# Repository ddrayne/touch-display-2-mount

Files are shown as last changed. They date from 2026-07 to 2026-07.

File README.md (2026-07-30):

# touch-display-2-mount

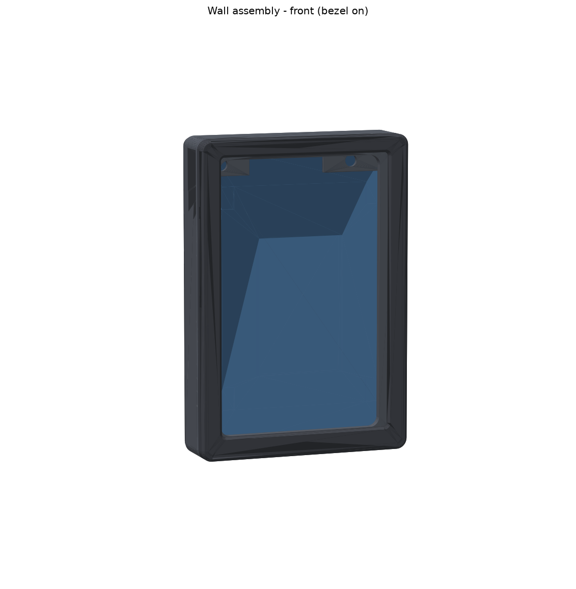
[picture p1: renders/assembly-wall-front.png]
Wall assembly


3D-printed mounts for the **Raspberry Pi Touch Display 2 – 10″ Portrait**
(with a Raspberry Pi 5 on its back): a three-part **gallery shadow-box wall
frame** (body + snap-on bezel + rear cover) that makes the display read as
framed art — ideal for dashboards, photo frames, and home-automation panels
— and a one-piece **desk stand**, plus two quick corner **fit coupons**.

Every dimension derives from the official product brief
(`docs/touch-display-2-10in-product-brief.pdf`, RP-010276-MM-1-10, July
2026), transcribed into `src/spec.py` — **with one measured correction: a
production unit is ~167 mm wide, not the drawing's 161.76** (the brief
itself warns its dimensions are approximate; height and active area check
out). If your unit differs, set `spec.UNIT_W` from calipers and rebuild.
The transcription was independently audited against the
drawing, and re-measured from the exported STLs by `src/verify.py` on every
build — including **assembly-path sweeps** that prove the display, bezel,
and cover can physically be installed and removed.

## Parts

**Slicing? Import the files in `print/`** — they are pre-rotated so the
correct face lands on the plate as imported (the `stl/` copies are in the
CAD's canonical coordinates for the verification harness and would import
three parts upside-down).

| File | What | Print orientation |
|---|---|---|
| `stl/frame.stl` | Wall-frame body, 174.2 × 254.53 × 45.8 mm | **Rear-face-down** (as exported) |
| `stl/bezel.stl` | Snap-on front bezel (the visible frame face) | Face-down (as exported) |
| `stl/cover.stl` | Posts-only vented rear cover | Rear-face-down |
| `stl/stand.stl` | Desk stand, 15° easel lean | Plate-face-down (as exported) |
| `stl/fit-coupon-body.stl` + `stl/fit-coupon-bezel.stl` | Corner fit gauges — **print these first** | As exported |
| `stl/_display_reference.stl` | Display solid for CAD reference — **do not print** | — |

3MF copies of each part sit alongside the STLs.

## How it works

The wall mount is **front-loading**. The body is an open-fronted shadow box
with an internal shelf ring; the display — with the Pi 5 already screwed to
its rear standoffs and protruding backward — drops in from the front and
its chassis rim rests on the shelf (the depth datum). The **bezel** then
slides over the body's recessed front band and clicks onto nine snap nubs
riding compliant tongues; foam pads on its back press the glass onto the
shelf. The lap seam between bezel skirt and body reads as a deliberate
1.5 mm shadow reveal around the frame.

The Pi + Active Cooler live in the deep, hidden cavity behind the shelf,
washed by seven hidden vent slots per side. The small **cover** enters
through the rear opening (passing under the keyhole tabs), lands on the
display's four M2.5 bobbin posts (121.8 × 160 mm pattern), and takes four
of the display's own supplied screws — it tidies the back, carries zip-tie
anchors, and lets the USB-C lead run to the bottom cable slot.

The rear edge carries a 6 mm shadow-wedge chamfer, so the hung frame
appears to float off the wall — and the side vents exhaust into that
hidden wedge while bottom-wall slots draw intake air, giving the Pi a
proper convection path. The frame hangs on **two wall screws 110 mm
apart** via keyhole tabs printed solidly into the rear face (print `docs/drilling-template.pdf` at 100 %
scale for the wall marks). The **desk stand** screws straight onto the same
four posts and leans the display 15° on curved easel cheeks, bottom edge
floating 14 mm above the desk, cable dropping through a notch in the tie
bar.

## Bill of materials

| Qty | Item | Used for |
|---|---|---|
| 1 | Raspberry Pi Camera Module 3 (standard, optional) | viewer-facing camera in the chin pod |
| 1 | Camera adapter cable for Pi 5 (standard-to-mini), 200 mm | Cam3 to the Pi 5's free MIPI port; routed length is ~125 mm, so 200 mm is ideal (the cable in the Cam3 box does not fit a Pi 5) |
| 4 | M2 × 4 mm self-tapping screws | camera board into the pod bosses |
| 4 | M2.5 screws — **the display's own supplied screws fit** | cover → display posts (or stand → posts) |
| 2 | 4 mm / #8 pan-head wall screws + plugs | hanging the frame |
| 8 | soft EVA foam pads, 2 mm thick, ~15 × 8 mm self-adhesive | bezel back, around the opening (compressed to ~1 mm) |
| 2–4 | small zip ties | cable dressing on the cover |
| 4 | stick-on rubber feet (optional) | stand feet |

No other fasteners: the bezel presses on — nine snap nubs ride compliant
tongues hidden in the body's front band, so it clicks home with fingertip
force and pulls off with a firm, even tug (start at the two finger reliefs
under the bottom edge). **Only ever remove the bezel with the frame on a
bench, face up — never on the wall** (with the bezel off, nothing retains
the display).

## Print settings (Bambu X1 / P1 / A1, 0.4 mm nozzle)

| | frame (body) | bezel (+ coupons) | cover | stand |
|---|---|---|---|---|
| Material | **PETG** | PETG (match body) | PETG | PLA or PETG |
| Layer / first | 0.20 / 0.20 | 0.20 / 0.20 | 0.20 / 0.20 | 0.20 / 0.25 |
| Walls | 4 | 4 | 3 | 4 |
| Infill | 15 % gyroid | 20 % | 25 % grid | 15 % gyroid |
| Supports | **OFF** | **OFF** | **OFF** | **OFF** |
| Brim / skirt / draft shield | **all OFF — mandatory** (254.5 mm part; paint-on brim ears in ±X only if wanted) | all OFF (same footprint) | off | off |
| Plate | textured PEI | **textured PEI** (this face is the visible front) | any | any |
| Special | disable X1 flow-calibration lines / check the A1 prime line in preview; place at bed centre manually; keep the seam OFF the snap nubs (paint it onto a corner) | elephant-foot comp ≤ 0.15; seam on a corner, off the recesses | 4 bottom layers (counterbore bridges); M2.5 heads sit ~0.4 mm proud of the shallow counterbores (hidden, harmless) | full fan above z ≈ 90 (thin prongs) |

- Everything is designed support-free **in the stated orientation**; the
  only down-facing features are deliberate short bridges (vent roofs, cable
  slot end, counterbore floors, liner-groove ceiling) verified by the
  overhang census in `verify.py`.
- Holes are pre-compensated +0.25 mm (community mounts for this display
  printed M2.5 holes undersized). Keyholes are Ø10 entry / 5 mm slot with
  lead-in chamfers.
- A matte filament hides layer sheen; the bezel's face picks up the plate
  texture, so a textured plate gives it a uniform powder-coat look.
- **Bambu Handy note:** Handy can't toggle brim/skirt on a raw STL — slice
  in Bambu Studio (or a MakerWorld draft) with the settings above, then
  send to the printer; Handy is fine for monitoring.

**Print the two fit coupons first** (~1.5 h) — and treat them as
measurement artifacts, not feel-tests: print them with the *identical*
material, profile, and plate you'll use for the real parts, caliper their
62 mm edges, and set the filament's shrinkage compensation from the
measured percentage before slicing the body and bezel (a coupon that feels
"snug but OK" can still bind over the full 254 mm). Then check the display
corner's slip fit, shelf seat, bezel lap and snap click. Too tight →
raise `spec.FIT_CLEAR` (display) or `params.LAP_CLEAR` (bezel); loose →
lower them; rebuild and re-print the coupons.

**Body and bezel must be printed in the same material, same profile, same
plate** — a PLA-on-PETG pairing can eat the entire 0.25 mm lap clearance
through differential shrinkage.

## Assembly (wall frame)

1. Stick the eight foam pads to the bezel's back face around the opening
   (over the bezel's solid border, outside the visible 2.5 mm reveal).
2. Screw the Pi 5 to the display's standoffs (supplied screws), connect the
   GPIO power lead and DSI ribbon.
3. Body face-up on the bench: lower the display in, glass up — chin (wider
   bezel) toward the cable slot — until the rim rests on the shelf.
4. Fit the cover through the rear opening onto the four posts; drive four
   supplied M2.5 screws. Zip-tie the USB-C lead to the anchors, out the
   bottom slot.
5. Press the bezel on until all nine nubs click.
6. Wall: print `docs/drilling-template.pdf` at 100 %, level it, drill/plug,
   leave the two screw heads ~4 mm proud, hang and slide down.

For the stand: same steps 2, then screw the stand plate onto the posts
(supplied screws) and route the cable through the tie-bar notch.

## Camera chin pod (optional)

`print/camera-pod.stl` (~20 g, ~1 h) hangs a Camera Module 3 under the
frame's chin, facing the viewer — ideal for presence-detection backlight
wake. No frame changes: two J-hooks tilt into the frame's inner pair of
bottom intake vents and gravity locks them (lift the pod's nose to remove).
Mount the camera board **ribbon-up** on the four M2 bosses (flip the image
in software: `libcamera` rotation 180), run the mini ribbon up the pod's
concealed tail channel and through the frame's cable slot to the Pi's free
MIPI port — connect it before hanging the frame. The lens aperture clears
the full 75° field of view (verified against pod, frame, and bezel).

## Care notes

- The stand tolerates normal touch use; very firm jabs at the top edge can
  rock any 15° easel — use the wall mount for enthusiastic households.
- A right-angle USB-C plug keeps the cable exit tidy on both mounts
  (straight plugs also fit — 13 mm of window clearance each side).

## Rebuilding / customising

```bash
pip install build123d trimesh shapely networkx rtree scipy matplotlib
cd src
python3 build_all.py     # builds STL+3MF, verifies (75 checks), renders
```

`src/spec.py` is the display (don't touch unless the drawing changes);
`src/params.py` is the design — reveal, wall, depth, tilt, clearances, snap
engagement — edit freely and rebuild; verification catches anything
unprintable, un-assemblable, or spec-breaking.

## Verification

- `src/verify.py`: 75 mesh-measured checks — integrity, the 121.8 × 160
  pattern position *and* diameters, bezel opening vs active area, shelf and
  felt datums, keyhole geometry incl. slot direction, bed fit, per-part
  overhang census, boolean interference against a worst-case display solid
  (which is itself audited against the spec), and translation sweeps along
  every assembly path. Report: `docs/verification-report.json`.
- Three independent multi-agent review rounds audited the drawing
  transcription, the STLs, printability, and the design; round 1's findings
  (including an assembly-impossibility proof against the v1 architecture)
  drove the current front-loading design.

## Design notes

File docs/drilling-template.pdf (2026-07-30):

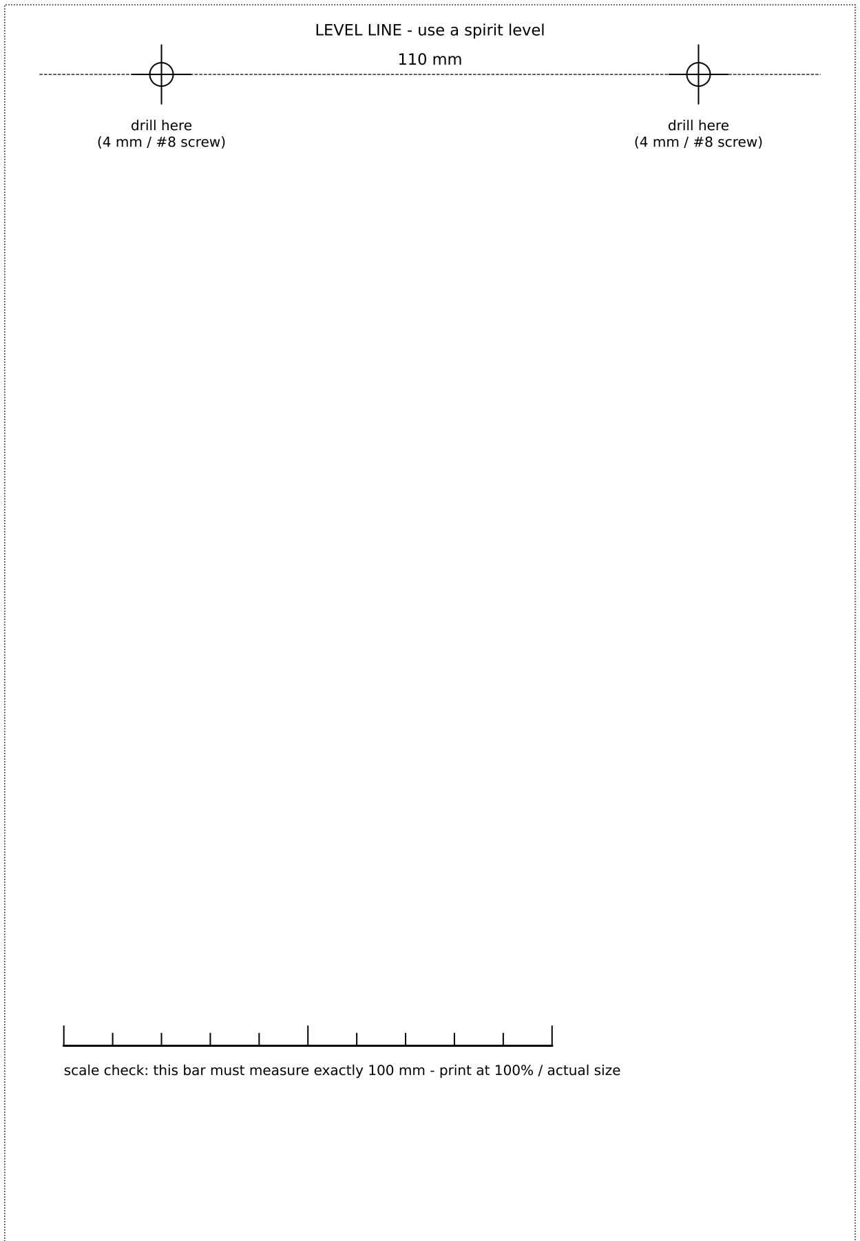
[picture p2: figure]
drill here (4 mm / #8 screw); LEVEL LINE - use a spirit level 110 mm

scale check: this bar must measure exactly 100 mm - print at 100% / actual size

Wall drilling template - Raspberry Pi Touch Display 2 10" Portrait mount Leave screw heads ~4 mm proud of the wall, hang the frame, slide down to lock.

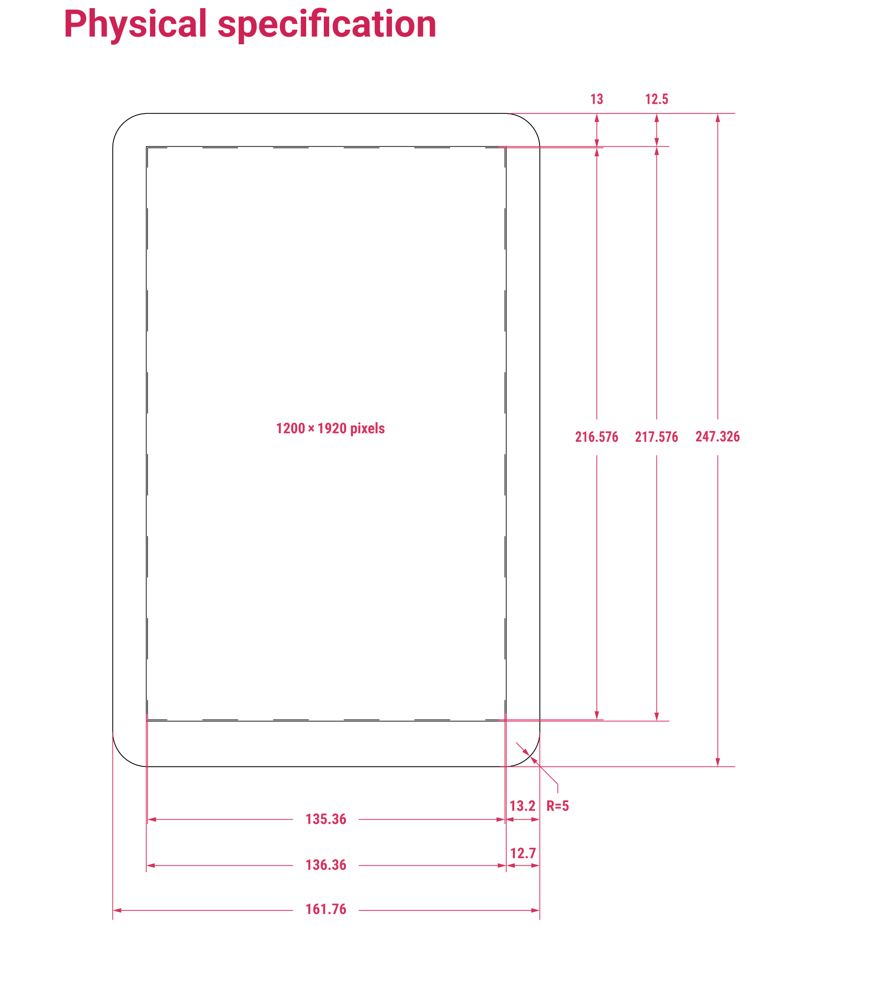
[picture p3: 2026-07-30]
docs/crop-front.png

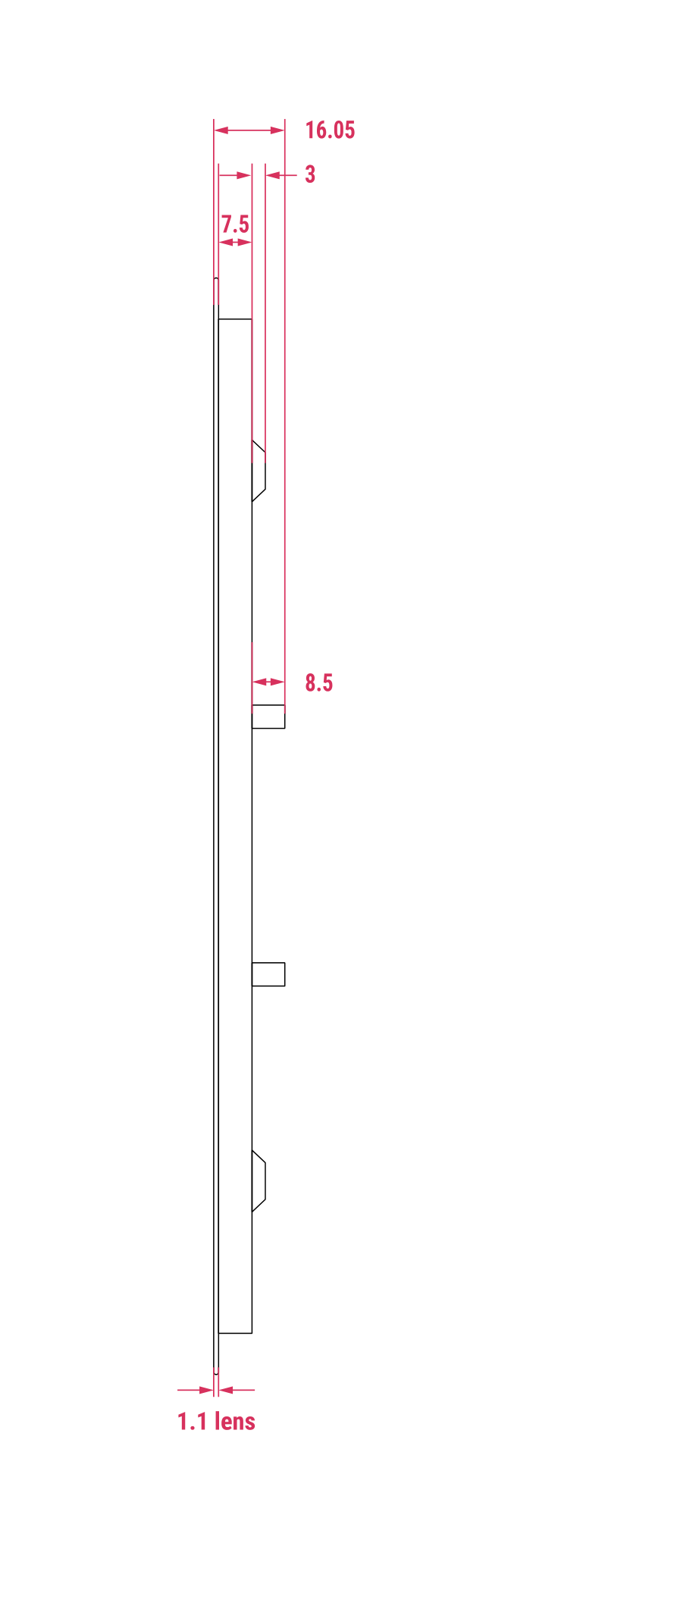
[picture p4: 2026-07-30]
docs/crop-side.png

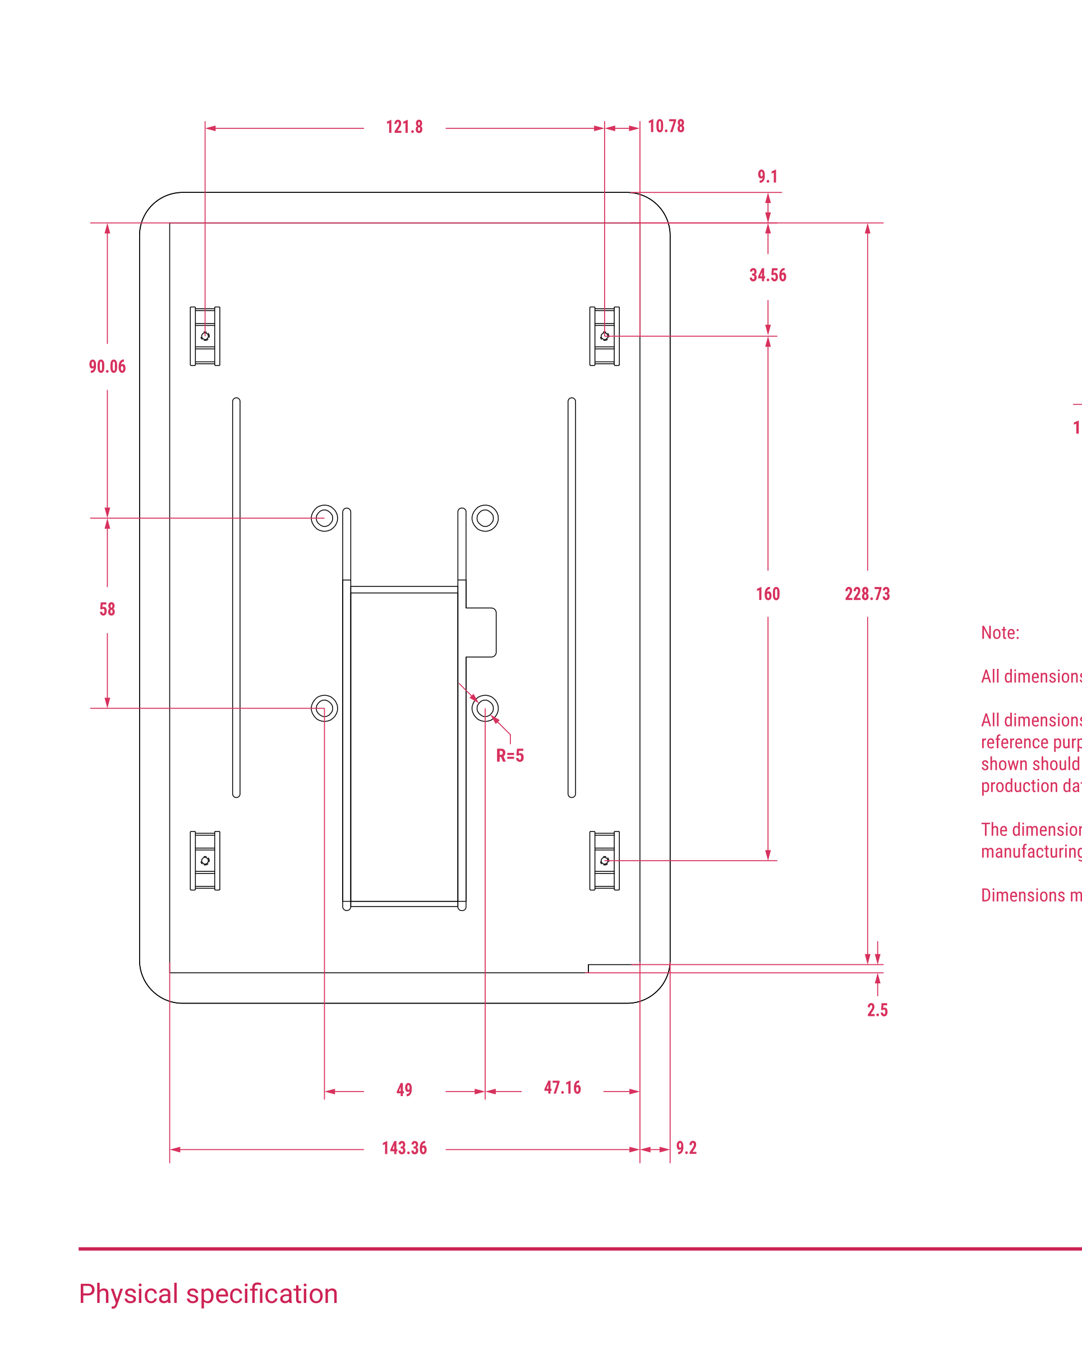
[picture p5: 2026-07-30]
docs/crop-rear.png

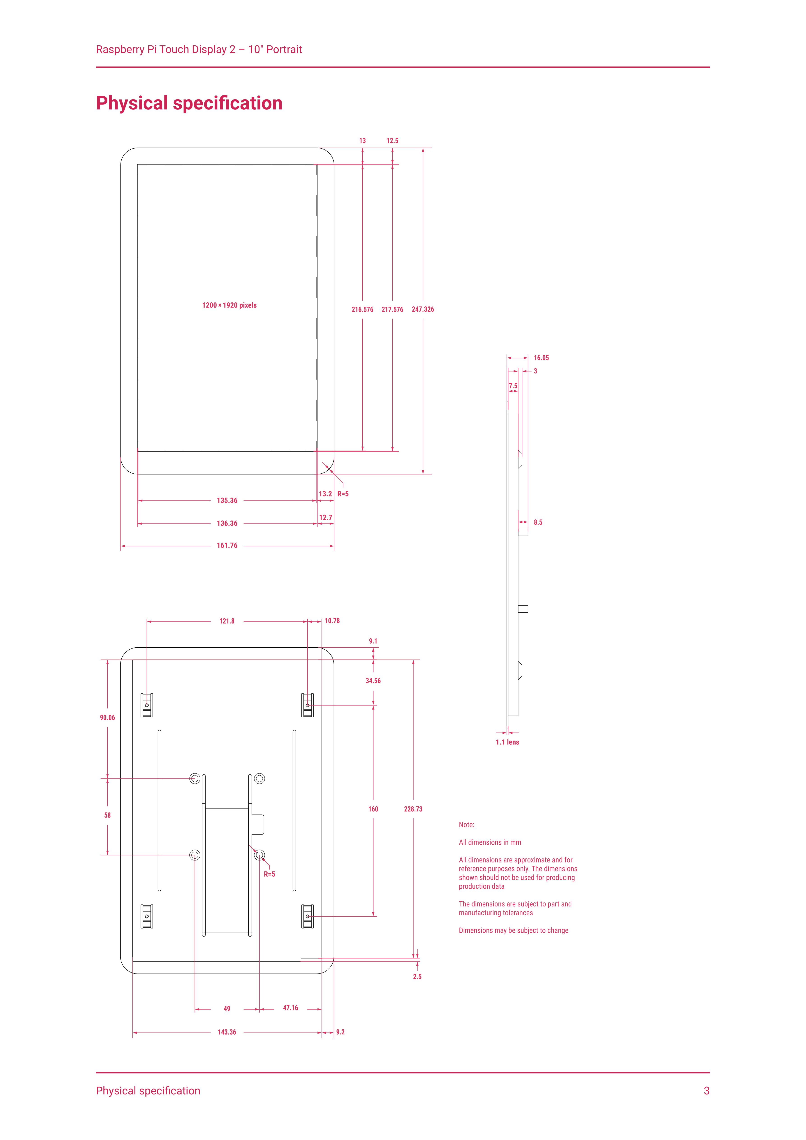
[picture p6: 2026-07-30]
docs/drawing-p4-full.png

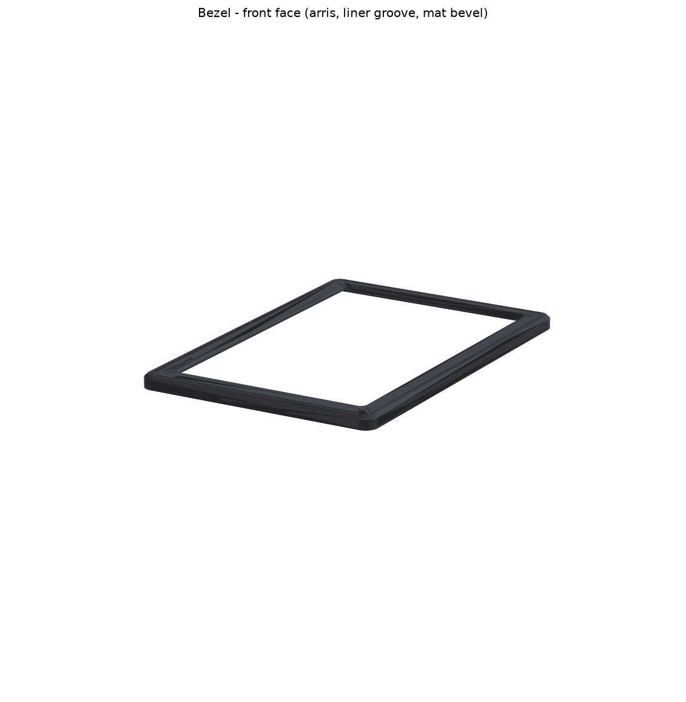
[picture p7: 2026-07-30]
renders/bezel-front.png

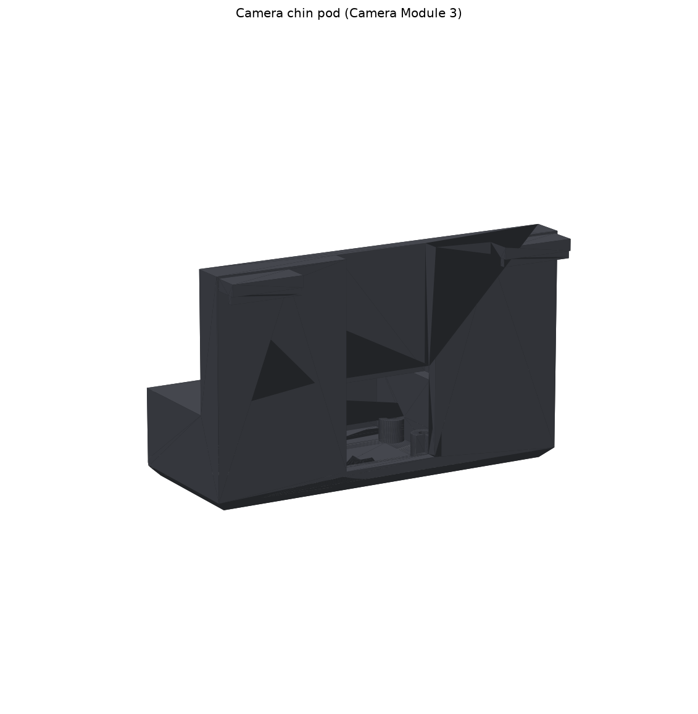
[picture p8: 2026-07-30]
renders/camera-pod.png

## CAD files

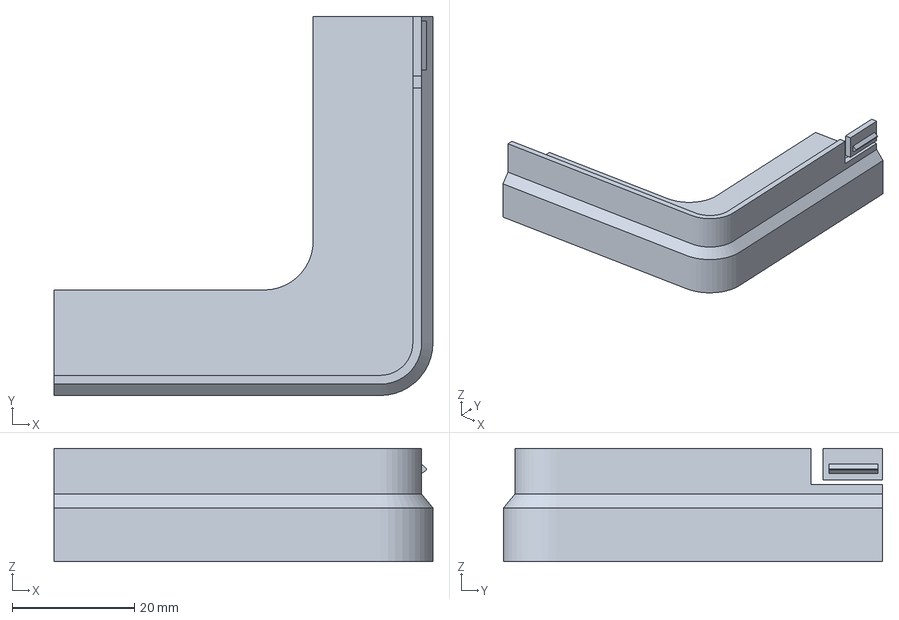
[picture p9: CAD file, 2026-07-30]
print/fit-coupon-body.3mf
62.0 x 62.0 x 18.5 mm

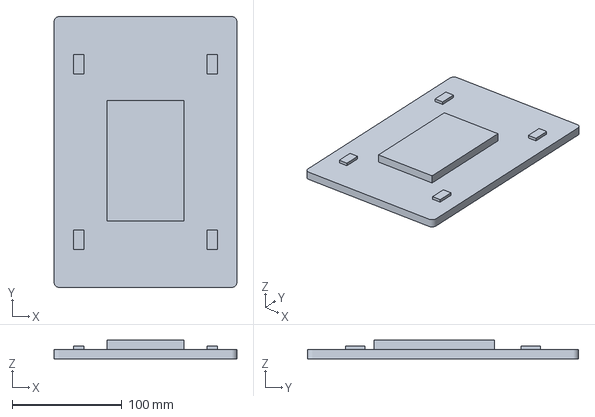
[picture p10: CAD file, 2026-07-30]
stl/_display_reference.3mf
167.0 x 247.3 x 17.1 mm

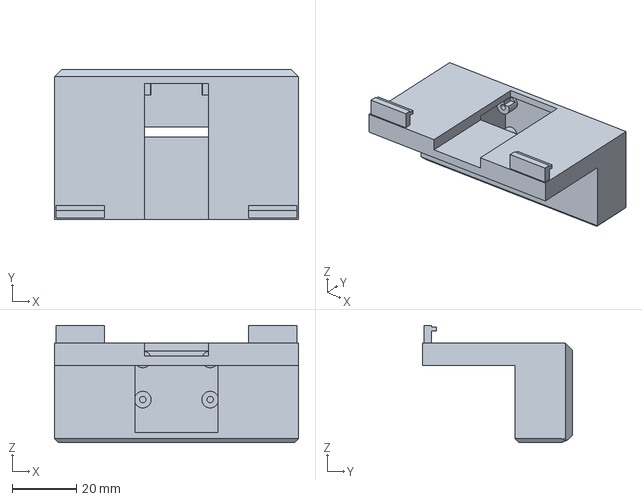
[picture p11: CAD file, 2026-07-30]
print/camera-pod.3mf
76.0 x 46.8 x 36.5 mm

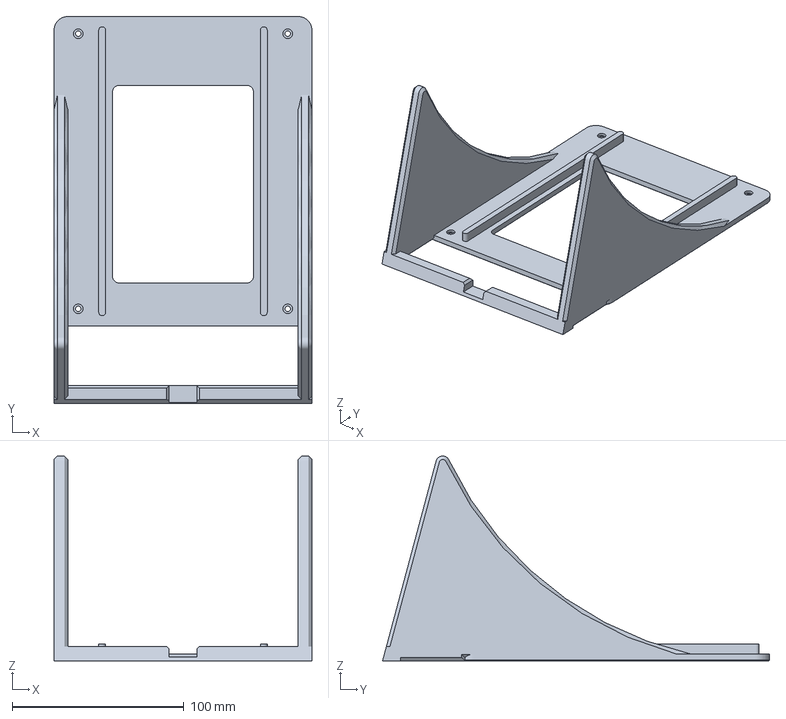
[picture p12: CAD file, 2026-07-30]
print/stand.3mf
150.0 x 225.0 x 119.2 mm

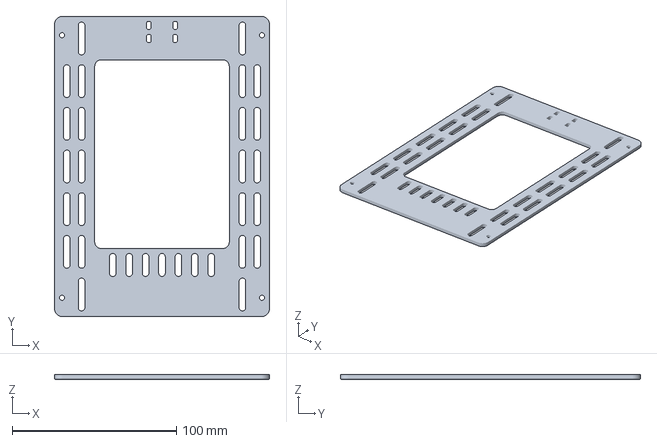
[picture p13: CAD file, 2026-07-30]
print/cover.3mf
131.0 x 183.0 x 3.00 mm

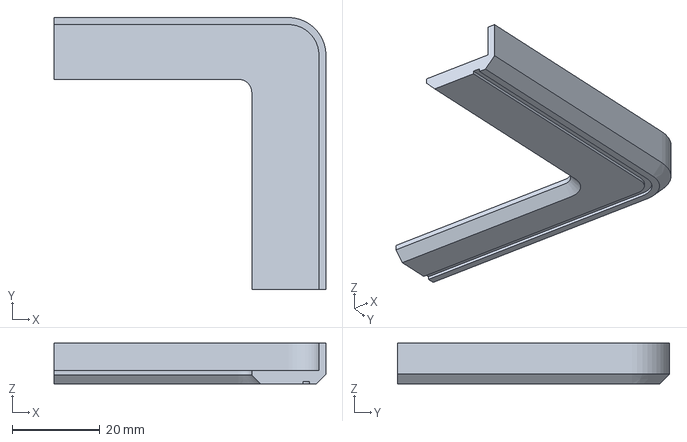
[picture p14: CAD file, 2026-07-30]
print/fit-coupon-bezel.3mf
62.0 x 62.0 x 9.30 mm

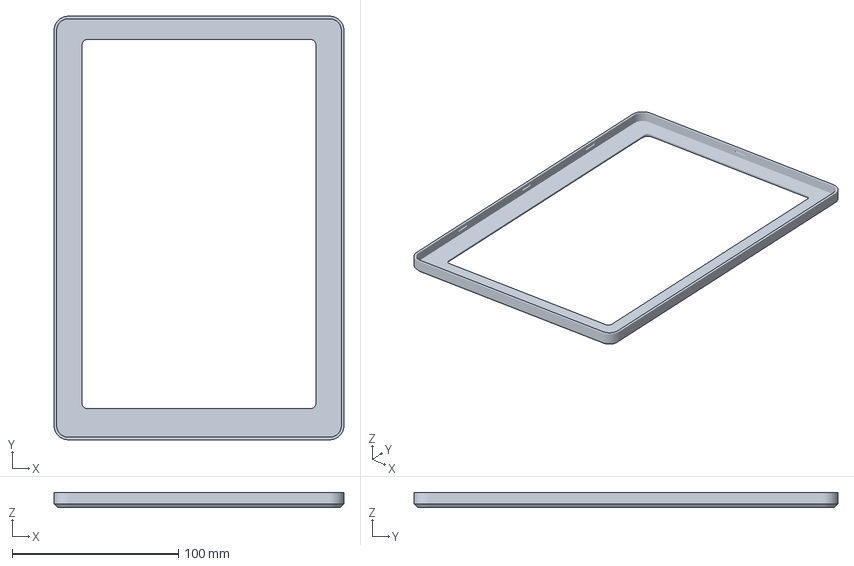
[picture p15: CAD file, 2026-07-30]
print/bezel.3mf
174.2 x 254.5 x 9.30 mm

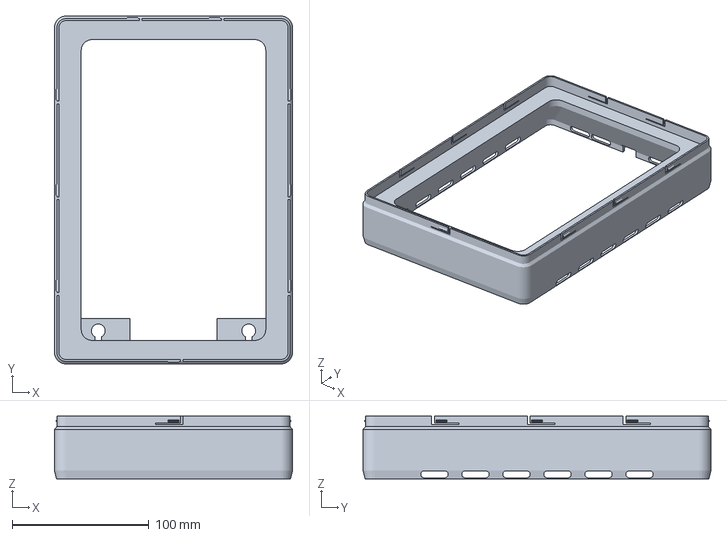
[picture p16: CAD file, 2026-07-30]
print/frame.3mf
174.2 x 254.5 x 45.8 mm

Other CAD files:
print/bezel.stl
print/camera-pod.stl
print/cover.stl
print/fit-coupon-bezel.stl
print/fit-coupon-body.stl
print/frame.stl
print/stand.stl
stl/_display_reference.stl
stl/bezel.3mf
stl/bezel.stl
stl/camera-pod.3mf
stl/camera-pod.stl
stl/cover.3mf
stl/cover.stl
stl/fit-coupon-bezel.3mf
stl/fit-coupon-bezel.stl
stl/fit-coupon-body.3mf
stl/fit-coupon-body.stl
stl/frame.3mf
stl/frame.stl
stl/stand.3mf
stl/stand.stl

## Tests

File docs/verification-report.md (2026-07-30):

# Verification history (Touch Display 2 10-inch mount)

The machine-readable current status lives in `verification-report.json`
(written by `src/verify.py` on every build). This file records the
independent review rounds and what they changed.

## Round 0 — spec transcription audit (before any CAD)

An independent reader re-measured the product-brief drawing (p4) at 20x
zoom and audited `src/spec.py`. **Blocker found and fixed:** the side-view
depth callouts were mis-attributed — the "3" callout belongs to the bobbin
posts (tips at 11.6 mm), the "8.5" to the Pi standoffs (deepest plane,
16.05 nominal / 17.1 worst case, the drawing being internally inconsistent
by 1.05 mm). Also captured: the rear-view "R=5" is the Pi-standoff boss
radius (Ø10), the rear plate is not vertically centred (9.1 top / 9.496
bottom insets), the bobbin keep-out is ~10 × 18 rectangular, and the
chassis is inset from the glass perimeter at the rim.

## Round 1 — three independent reviews of the v1 build

- **Design review:** keyhole entry too small for screw heads; cover
  counterbores broke out of the part edge; proposed the mat bevel, arris,
  liner groove, shadow reveal, easel-arc stand, and top-vent deletion.
- **Printability review:** confirmed the keyhole blocker (only hole with no
  print compensation); keyhole tabs were corner-anchored bridge islands;
  M3×8 bottomed out in the rib pilots; rib ramps measured 54.1°.
- **Spec/assembly audit:** every static dimension measured correct to
  ±0.005 mm, **but a swept-path boolean proved the display could not be
  inserted past the cover-seat ribs and keyhole tabs at all** — the v1
  frame was un-assemblable, and the 51-check harness had no check that
  could catch it. The display reference solid's connector hump was also
  0.95 mm shallower than its stated worst-case bound.

## v2 response (current architecture)

Front-loading: internal shelf ring seats the display (depth datum
8.75 mm), snap-on bezel with lap-seam reveal and felt preload closes the
face, cover shrinks to a posts-only vented panel using the display's own
screws, keyhole tabs print solid on the bed (orientation flipped to
rear-face-down), keyholes enlarged to Ø10/5 with lead-ins, shelf rear
carries a ≤45° printable chamfer, display mock rebuilt fully worst-case,
and `verify.py` grew: mock self-audit, hole diameter assertions, keyhole
slot-direction check, felt/datum stack checks, and boolean translation
sweeps along every assembly path (display in/out the front, bezel on/off,
cover in/out the rear). 64/64 checks pass.

## Round 2 — three fresh adversarial reviews of v2

Recorded in the repository history alongside any fixes they produced; the
build shipped only after a clean round.

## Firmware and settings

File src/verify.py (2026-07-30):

"""Geometric verification harness for the Touch Display 2 mount STLs.

Run after (re)building the STLs:  python3 build_all.py

Checks every exported mesh against src/spec.py (the audited transcription of
the official drawing) and src/params.py (the design intent):
  - mesh integrity: watertight, consistent winding
  - the display reference solid is itself audited against spec.py (bounding
    box, depth planes, post/standoff/hump positions) so the interference
    proofs cannot pass vacuously
  - ASSEMBLY-PATH sweeps, not just static fits: the display is swept out
    through the front, the cover swept out through the rear (below the
    keyhole tabs), each step boolean-checked against the body
  - hole positions AND diameters (121.8 x 160 pattern, keyhole entry/slot)
  - bezel opening vs the active area; shelf seat plane; felt-gap stack
  - bed fit and per-part print-orientation overhang census
  - stand ground-plane contact on the tilted ground

Exit code 0 = everything passed. JSON report: docs/verification-report.json.
"""

import json
import math
import os
import sys

import numpy as np
import shapely.geometry as sg
import trimesh

import spec
import params as p

HERE = os.path.dirname(os.path.abspath(__file__))
STL = os.path.join(HERE, "..", "stl")
RESULTS = []


def check(name, ok, detail=""):
    RESULTS.append({"name": name, "ok": bool(ok), "detail": str(detail)})
    print(f"{'PASS' if ok else 'FAIL'}  {name}  {detail}")
    return ok


def load(name):
    return trimesh.load(os.path.join(STL, name), force="mesh")


def section_polys(mesh, z):
    sec = mesh.section(plane_origin=[0, 0, z], plane_normal=[0, 0, 1])
    if sec is None:
        return []
    to_plane = np.eye(4)
    to_plane[2, 3] = -z
    planar, _ = sec.to_2D(to_2D=to_plane)
    return list(planar.polygons_full)


def ring_centres(mesh, z, max_area=200.0):
    holes = []
    for poly in section_polys(mesh, z):
        for hole in poly.interiors:
            hp = sg.Polygon(hole)
            if hp.area <= max_area:
                c = hp.centroid
                holes.append((c.x, c.y, hp.area))
    return holes


def outer_bounds(mesh, z):
    polys = section_polys(mesh, z)
    if not polys:
        return None
    xs, ys = [], []
    for poly in polys:
        bx = poly.bounds
        xs += [bx[0], bx[2]]
        ys += [bx[1], bx[3]]
    return min(xs), min(ys), max(xs), max(ys)


def interior_bounds(mesh, z):
    best = None
    for poly in section_polys(mesh, z):
        for hole in poly.interiors:
            hp = sg.Polygon(hole)
            if best is None or hp.area > best.area:
                best = hp
    return best.bounds if best is not None else None


def expect_holes(mesh, z, expected, tol, label, dia=None, dia_tol=0.3, max_area=200.0):
    found = ring_centres(mesh, z, max_area=max_area)
    ok_all = True
    for ex, ey in expected:
        match = [h for h in found if abs(h[0] - ex) < tol and abs(h[1] - ey) < tol]
        if not match:
            ok_all = False
            check(f"{label} hole @({ex:.2f},{ey:.2f})", False, "not found in section")
            continue
        d = 2 * math.sqrt(match[0][2] / math.pi)
        if dia is not None:
            ok = abs(d - dia) < dia_tol
            ok_all &= check(
                f"{label} hole @({ex:.2f},{ey:.2f})", ok, f"d {d:.2f} (want {dia:.2f})"
            )
        else:
            check(f"{label} hole @({ex:.2f},{ey:.2f})", True, f"d~{d:.2f}")
    return ok_all


def overhang_area(mesh, down, bed_z, exempt=None, limit_deg=55.0):
    n = mesh.face_normals
    downness = n @ np.array(down, dtype=float)
    steep = downness > math.sin(math.radians(limit_deg - 0.5))
    centres = mesh.triangles_center
    d_axis = np.array(down, dtype=float)
    bed_pt = np.array([0, 0, bed_z], dtype=float)
    dist = (centres - bed_pt) @ (-d_axis)
    mask = steep & (dist > 0.2)
    if exempt:
        for lo, hi in exempt:
            inside = np.all((centres >= lo) & (centres <= hi), axis=1)
            mask &= ~inside
    return float(mesh.area_faces[mask].sum()), centres[mask]


def inter_volume(a, b):
    try:
        inter = trimesh.boolean.intersection([a, b], engine="manifold")
        return 0.0 if inter is None or inter.is_empty else abs(inter.volume)
    except Exception:
        return float("nan")


def interference(a, b, label, allow=1.0):
    vol = inter_volume(a, b)
    if math.isnan(vol):
        return check(f"interference {label}", False, "boolean failed")
    return check(f"interference {label}", vol < allow, f"intersection {vol:.3f} mm3")


def sweep_clear(moving, fixed, direction, steps, label, allow=1.0):
    """Boolean-check `moving` translated along `direction` at each step."""
    worst = 0.0
    for s in steps:
        m = moving.copy()
        m.apply_translation(np.array(direction, dtype=float) * s)
        v = inter_volume(m, fixed)
        if math.isnan(v):
            return check(f"sweep {label}", False, f"boolean failed at {s}")
        worst = max(worst, v)
    return check(f"sweep {label}", worst < allow, f"worst intersection {worst:.3f} mm3")


POSTS = [
    (sx * spec.POST_SPACING_X / 2, sy * spec.POST_SPACING_Y / 2)
    for sx in (-1, 1)
    for sy in (-1, 1)
]


def verify_mock(display):
    """Audit the display reference solid itself against spec.py."""
    check("mock watertight", display.is_watertight)
    ext = display.extents
    check(
        "mock bbox = unit + worst depth",
        abs(ext[0] - spec.UNIT_W) < 0.05
        and abs(ext[1] - spec.UNIT_H) < 0.05
        and abs(ext[2] - spec.UNIT_DEPTH_WORST) < 0.05,
        f"{ext[0]:.2f} x {ext[1]:.2f} x {ext[2]:.2f}",
    )
    # bobbin posts present at the right places at post-tip depth
    ob = outer_bounds(display, spec.POST_TIP_Z - 0.5)
    ok = ob is not None and abs(ob[2] - (spec.POST_SPACING_X / 2 + (spec.POST_BOBBIN_W + 0.7) / 2)) < 0.3
    check("mock bobbin extent", ok, str(ob))
    polys = section_polys(display, spec.POST_TIP_Z - 0.5)
    n_feats = len(polys)
    check("mock features at post plane", n_feats >= 5, f"{n_feats} regions (4 posts + hump)")
    # deepest plane: hump + standoffs both reach the 17.1 worst case (the
    # standoffs sit inside the hump's XY envelope, so the section is one
    # large region spanning the hump extents)
    polys = section_polys(display, spec.UNIT_DEPTH_WORST - 0.2)
    ok = False
    detail = "no regions"
    for q in polys:
        b = sg.Polygon(q.exterior).bounds
        if (
            abs(b[0] + spec.HUMP_HALF_W) < 0.3
            and abs(b[2] - spec.HUMP_HALF_W) < 0.3
            and abs(b[1] - spec.HUMP_Y_MIN) < 0.3
            and abs(b[3] - spec.HUMP_Y_MAX) < 0.3
        ):
            ok = True
            detail = f"hump {b[0]:.1f}..{b[2]:.1f} x {b[1]:.1f}..{b[3]:.1f} at 17.1"
    check("mock hump+standoffs at 17.1 worst-case", ok, detail)


def verify_frame(display, cover_mesh):
    m = load("frame.stl")
    check("body watertight", m.is_watertight)
    check("body winding", m.is_winding_consistent)
    ext = m.extents
    check(
        "body bed fit",
        ext[0] <= spec.BED_LIMIT and ext[1] <= spec.BED_LIMIT,
        f"{ext[0]:.1f} x {ext[1]:.1f}",
    )
    check(
        "body bbox",
        abs(ext[0] - p.OUT_W) < 0.05
        and abs(ext[1] - p.OUT_H) < 0.05
        and abs(m.bounds[0][2] - p.BAND_TOP_Z) < 0.02
        and abs(m.bounds[1][2] - p.FRAME_REAR_Z) < 0.02,
        f"{ext[0]:.2f} x {ext[1]:.2f}, z {m.bounds[0][2]:.2f}..{m.bounds[1][2]:.2f}",
    )

    ib = interior_bounds(m, 4.0)
    if ib:
        w, h = ib[2] - ib[0], ib[3] - ib[1]
        check(
            "body cavity = display + clearance",
            abs(w - p.CAV_W) < 0.1 and abs(h - p.CAV_H) < 0.1,
            f"{w:.2f} x {h:.2f} (want {p.CAV_W:.2f} x {p.CAV_H:.2f})",
        )
    ob = outer_bounds(m, 0.8)  # below the snap nubs
    check(
        "body front band recessed for the skirt",
        ob is not None and abs((ob[2] - ob[0]) - p.BAND_OUT_W) < 0.1,
        f"band {ob[2]-ob[0]:.2f} (want {p.BAND_OUT_W:.2f})",
    )
    ib = interior_bounds(m, p.SHELF_FRONT_Z + p.SHELF_T / 2)
    if ib:
        w, h = ib[2] - ib[0], ib[3] - ib[1]
        check(
            "shelf opening",
            abs(w - p.SHELF_OPEN_W) < 0.1 and abs(h - p.SHELF_OPEN_H) < 0.1,
            f"{w:.2f} x {h:.2f}",
        )
    # shelf seat plane: substantial up-facing area at SHELF_FRONT_Z
    seat = m.area_faces[
        (np.abs(m.triangles_center[:, 2] - p.SHELF_FRONT_Z) < 0.05)
        & (m.face_normals[:, 2] < -0.99)
    ].sum()
    check("shelf seat plane area", seat > 4000, f"{seat:.0f} mm2 at z={p.SHELF_FRONT_Z}")

    # keyholes: position, diameter, slot direction
    kz = p.KEYHOLE_TAB_Z + p.KEYHOLE_TAB_T / 2
    holes = ring_centres(m, kz, max_area=250)
    for sx in (-1, 1):
        matches = [
            h
            for h in holes
            if abs(h[0] - sx * p.KEYHOLE_X) < 4 and abs(h[1] - (p.KEYHOLE_ENTRY_Y + 3)) < 6
        ]
        area_ok = matches and 104 < matches[0][2] < 130
        check(
            f"keyhole @x={sx * p.KEYHOLE_X:.0f}",
            bool(area_ok),
            f"ring area {matches[0][2]:.0f}" if matches else "not found",
        )
    probes = np.array(
        [
            [p.KEYHOLE_X, p.KEYHOLE_ENTRY_Y + p.KEYHOLE_SLOT_LEN + 1, kz],
            [-p.KEYHOLE_X, p.KEYHOLE_ENTRY_Y + p.KEYHOLE_SLOT_LEN + 1, kz],
            [p.KEYHOLE_X, p.KEYHOLE_ENTRY_Y - 8.5, kz],
        ]
    )
    inside = m.contains(probes)
    check(
        "keyhole slot runs upward",
        (not inside[0]) and (not inside[1]) and inside[2],
        f"void above entry {~inside[0]}/{~inside[1]}, solid below {inside[2]}",
    )
    entry_d = 2 * math.sqrt((max(h[2] for h in holes) - p.KEYHOLE_SLOT_W * p.KEYHOLE_SLOT_LEN - math.pi * (p.KEYHOLE_SLOT_W / 2) ** 2 / 2) / math.pi) if holes else 0

    # snap nubs present
    nub_probe = np.array(
        [
            [p.BAND_OUT_W / 2 + 0.4, 70, (p.NUB_Z0 + p.NUB_Z1) / 2],
            [p.BAND_OUT_W / 2 + 0.4, 35, (p.NUB_Z0 + p.NUB_Z1) / 2],
        ]
    )
    nin = m.contains(nub_probe)
    check("snap nubs on band", nin[0] and not nin[1], f"nub {nin[0]}, gap {nin[1]}")

    # vents + cable slot voids
    v = m.contains(
        np.array(
            [
                [p.CAV_W / 2 + p.WALL / 2, 15.0, p.VENT_Z],
                [0, -(p.CAV_H / 2 + p.WALL / 2), p.FRAME_REAR_Z - 4],
            ]
        )
    )
    check("side vents + cable slot open", (not v[0]) and (not v[1]), str(v))

    # print orientation: rear-face-down -> down = +Z
    exempt = [
        # vent slot front faces (deliberate 3.3 mm-wall bridges), including
        # the bottom-wall intake slots near y = -125
        (
            np.array([-p.OUT_W / 2 - 1, -130, p.VENT_Z - p.VENT_H / 2 - 0.3]),
            np.array([p.OUT_W / 2 + 1, 130, p.VENT_Z - p.VENT_H / 2 + 0.7]),
        ),
        # cable slot end face (14 mm bridge)
        (
            np.array([-p.CABLE_SLOT_W, -p.OUT_H / 2 - 1, p.CABLE_SLOT_FRONT_Z - 0.3]),
            np.array([p.CABLE_SLOT_W, -p.CAV_H / 2 + 1, p.CABLE_SLOT_FRONT_Z + 0.3]),
        ),
        # finger-relief roofs (as printed): two 18 x 1.2 mm micro-bridges
        (
            np.array([-70, -p.OUT_H / 2 - 1, 2.9]),
            np.array([70, -p.BAND_OUT_H / 2 + 2, 3.1]),
        ),
        # tongue-slit ceilings and tongue undersides: 1.45 mm-wide strips
        # bridging the 2 mm tip slits / 0.75 mm horizontal slits, anchored
        # at both ends, hidden behind the bezel skirt
        (
            np.array([-p.OUT_W / 2 - 1, -p.OUT_H / 2 - 1, p.TONGUE_SLIT_TOP - 0.15]),
            np.array([p.OUT_W / 2 + 1, p.OUT_H / 2 + 1, p.TONGUE_SLIT_TOP + 0.15]),
        ),
        (
            np.array([-p.OUT_W / 2 - 1, -p.OUT_H / 2 - 1, p.TONGUE_TOP_Z - 0.15]),
            np.array([p.OUT_W / 2 + 1, p.OUT_H / 2 + 1, p.TONGUE_TOP_Z + 0.15]),
        ),
    ]
    area, flagged = overhang_area(m, [0, 0, 1], p.FRAME_REAR_Z, exempt)
    check("body support-free (rear-face-down)", area < 40, f"unsupported {area:.0f} mm2")

    # first-layer wall widths at the bed (rear face): a filter regression
    # like round 2's inner-rim chamfer would show up as a sub-mm ring here
    bed_pts = []
    for y in (-60.0, 0.0, 60.0):
        for w in np.arange(0.2, 3.4, 0.1):
            bed_pts.append([p.CAV_W / 2 + w, y, p.FRAME_REAR_Z - 0.1])
            bed_pts.append([-p.CAV_W / 2 - w, y, p.FRAME_REAR_Z - 0.1])
    for x in (-40.0, 40.0):
        for w in np.arange(0.2, 3.4, 0.1):
            bed_pts.append([x, -p.CAV_H / 2 - w, p.FRAME_REAR_Z - 0.1])
    inside = m.contains(np.array(bed_pts))
    per_station = inside.reshape(-1, 32).sum(axis=1) * 0.1 if False else None
    widths = []
    n_w = len(list(np.arange(0.2, 3.4, 0.1)))
    for i in range(0, len(bed_pts), n_w):
        pass
    # group: stations alternate in construction; simpler recount
    stations = {}
    for pt, isin in zip(bed_pts, inside):
        key = (round(pt[0], 1) if abs(pt[1]) > 100 else (pt[1], np.sign(pt[0])))
        stations.setdefault(str(key), 0)
        stations[str(key)] += 0.1 if isin else 0
    bad = {k: round(v, 2) for k, v in stations.items() if not 1.3 <= v <= 2.4}
    check("first-layer ring width uniform ~1.8", not bad, f"outliers: {bad}" if bad else "8 stations 1.3-2.4 mm")

    # seat contact: the shelf ring must land on the display's REAR PLATE
    # (143.36 x 228.73, vertically offset +0.198), not on air. Analytic
    # strips from the measured shelf opening vs the spec plate outline.
    ib = interior_bounds(m, p.SHELF_FRONT_Z + 1.0)
    if ib:
        plate_cy = (spec.REAR_PLATE_INSET_BOTTOM - spec.REAR_PLATE_INSET_TOP) / 2
        strip_x = spec.REAR_PLATE_W / 2 - ib[2]
        strip_top = (plate_cy + spec.REAR_PLATE_H / 2) - ib[3]
        strip_bot = (spec.REAR_PLATE_H / 2 - plate_cy) + ib[1]
        worst = min(strip_x, strip_top, strip_bot) - spec.FIT_CLEAR - 0.25
        check(
            "shelf seats on the display rear plate",
            worst >= 3.0,
            f"strips x/top/bot {strip_x:.2f}/{strip_top:.2f}/{strip_bot:.2f}, worst-case {worst:.2f}",
        )

    # tongue slits present (compliant snaps, not a rigid ring)
    probe = np.array(
        [
            [p.BAND_OUT_W / 2 - 0.7, 70 + p.NUB_TIP_OFFSET + p.TONGUE_SLIT_W / 2, 2.0],
            [p.BAND_OUT_W / 2 - 0.7, 70, (p.TONGUE_TOP_Z + p.TONGUE_SLIT_TOP) / 2],
        ]
    )
    tin = m.contains(probe)
    check("snap tongues freed by slits", (not tin[0]) and (not tin[1]), str(tin))

    # static + swept interference (display SEATED = +0.15 on the shelf)
    seated = display.copy()
    seated.apply_translation([0, 0, p.SHELF_FRONT_Z - spec.EDGE_T])
    interference(m, seated, "body vs display (seated)")
    sweep_clear(
        seated,
        m,
        [0, 0, -1],
        [3, 6, 10, 15, 20, 30, 45, 60],
        "display OUT through the front",
    )
    cov_seated = cover_mesh.copy()
    cov_seated.apply_translation([0, 0, p.SHELF_FRONT_Z - spec.EDGE_T])
    sweep_clear(
        cov_seated,
        m,
        [0, 0, 1],
        [3, 6, 10, 15, 20, 26, 31, 40, 60],
        "cover OUT through the rear (below tabs)",
    )
    # service path: display + cover as one assembly out through the front
    service = trimesh.util.concatenate([seated, cov_seated])
    sweep_clear(
        service,
        m,
        [0, 0, -1],
        [3, 6, 10, 15, 20, 30, 45, 60],
        "display+cover service removal out the front",
    )
    return m


def verify_bezel(display, body):
    m = load("bezel.stl")
    check("bezel watertight", m.is_watertight)
    check("bezel winding", m.is_winding_consistent)
    ext = m.extents
    check(
        "bezel bbox",
        abs(ext[0] - p.OUT_W) < 0.05
        and abs(ext[1] - p.OUT_H) < 0.05
        and abs(m.bounds[0][2] - p.BEZEL_FRONT_Z) < 0.02,
        f"{ext[0]:.2f} x {ext[1]:.2f}, z from {m.bounds[0][2]:.2f}",
    )
    ib = interior_bounds(m, p.BEZEL_FRONT_Z + p.BEZEL_FACE_T - 0.3)
    if ib:
        w, h = ib[2] - ib[0], ib[3] - ib[1]
        cy = (ib[1] + ib[3]) / 2
        check(
            "bezel opening",
            abs(w - p.LIP_OPEN_W) < 0.15 and abs(h - p.LIP_OPEN_H) < 0.15 and abs(cy - p.LIP_OPEN_CY) < 0.1,
            f"{w:.2f} x {h:.2f} cy {cy:.2f}",
        )
        # opening contains the active area with >= 2.3 margin, and the mat
        # bevel at the front face widens it (no pixel occlusion at angle)
        check(
            "active-area keep-out",
            w >= spec.ACTIVE_W + 2 * 2.3 and h >= spec.ACTIVE_H + 2 * 2.3,
            f"margins {(w - spec.ACTIVE_W)/2:.2f}/{(h - spec.ACTIVE_H)/2:.2f}",
        )
    fb = interior_bounds(m, p.BEZEL_FRONT_Z + 0.2)
    if fb:
        check(
            "mat bevel opens toward the face",
            (fb[2] - fb[0]) > p.LIP_OPEN_W + 2 * (p.MAT_BEVEL - 0.6),
            f"front opening {fb[2]-fb[0]:.2f}",
        )
    # tongue slits fully hidden + true seam reveal
    skirt_end = float(m.bounds[1][2])
    check(
        "skirt covers the tongue slits",
        skirt_end >= p.TONGUE_SLIT_TOP + 0.08,
        f"skirt end z {skirt_end:.2f} vs slit top {p.TONGUE_SLIT_TOP}",
    )
    reveal = (p.BAND_TOP_Z + p.BAND_DEPTH) - skirt_end
    check("seam reveal is the documented 1.5", abs(reveal - 1.5) < 0.05, f"{reveal:.2f} mm")

    # plate back plane (felt datum)
    back = m.area_faces[
        (np.abs(m.triangles_center[:, 2] - p.BEZEL_BACK_Z) < 0.05)
        & (m.face_normals[:, 2] > 0.99)
    ].sum()
    check("bezel felt datum plane", back > 3000, f"{back:.0f} mm2 at z={p.BEZEL_BACK_Z}")
    # felt gap arithmetic: glass sits at GLASS_Z on the shelf
    gap = p.GLASS_Z - p.BEZEL_BACK_Z
    check("pad gap", abs(gap - p.BEZEL_PAD_GAP) < 0.01, f"{gap:.2f} mm for 2 mm foam pads")

    # over-insertion stop: the snap (not the band rim) sets depth, with a
    # deliberate gap before the plate back can bottom on the band
    gap = p.BAND_TOP_Z - p.BEZEL_BACK_Z
    check("bezel over-insertion stop gap", abs(gap - 0.3) < 0.01, f"{gap:.2f} mm")

    # assembled bezel does not hit body or display; the snap event is the
    # ONLY interference along the slide (nub band), and it is small enough
    # for the tongue springs (~2 N each) to absorb
    seat_v = inter_volume(m, body)
    check(
        "bezel seats without stress (exact-touch on retention faces)",
        seat_v < 0.5,
        f"seat interference {seat_v:.2f} mm3",
    )
    fwd = m.copy()
    fwd.apply_translation([0, 0, -0.1])
    fwd_v = inter_volume(fwd, body)
    check(
        "zero-float: recess wedges within 0.1 mm of forward travel",
        fwd_v > 0.05,
        f"{fwd_v:.2f} mm3 at 0.1 forward (round-2 dead-band was 0.30-0.66)",
    )
    seated_disp = display.copy()
    seated_disp.apply_translation([0, 0, p.SHELF_FRONT_Z - spec.EDGE_T])
    interference(m, seated_disp, "bezel vs display (seated)")
    sweep_clear(m, seated_disp, [0, 0, -1], [2, 5, 10], "bezel OFF the front vs display")
    peak = 0.0
    for s_ in (0.6, 1.0, 1.4, 1.8, 2.2, 2.6, 3.0):
        b = m.copy()
        b.apply_translation([0, 0, -s_])
        v = inter_volume(b, body)
        peak = max(peak, 0.0 if math.isnan(v) else v)
    check(
        "bezel snap travel (tongue deflection only)",
        0.0 < peak < 60.0,
        f"peak traveling interference {peak:.1f} mm3 across 9 tongues",
    )

    # screw arithmetic: the display's supplied short M2.5s must engage the
    # bobbin threads through cover and stand
    cover_grip = p.COVER_T - p.POST_CBORE_DEPTH
    stand_grip = p.STAND_PLATE_T - p.POST_CBORE_DEPTH
    check(
        "supplied M2.5 screws engage (cover/stand)",
        cover_grip <= 2.5 and stand_grip <= 3.0,
        f"under-head stack {cover_grip:.1f} / {stand_grip:.1f} mm of a ~6 mm screw",
    )

    # deliberate micro-features: the liner groove's 1.5 mm ceiling ring and
    # the snap-recess floors (0.9 mm ledges hidden inside the lap joint)
    liner_exempt = [
        (
            np.array([-p.OUT_W / 2, -p.OUT_H / 2, p.BEZEL_FRONT_Z + p.LINER_GROOVE_D - 0.3]),
            np.array([p.OUT_W / 2, p.OUT_H / 2, p.BEZEL_FRONT_Z + p.LINER_GROOVE_D + 0.3]),
        ),
        (
            np.array([-p.OUT_W / 2, -p.OUT_H / 2, p.RECESS_Z0 - 0.3]),
            np.array([p.OUT_W / 2, p.OUT_H / 2, p.RECESS_Z1 + 0.3]),
        ),
    ]
    area, _ = overhang_area(m, [0, 0, -1], p.BEZEL_FRONT_Z, liner_exempt)
    check("bezel support-free (face-down)", area < 30, f"unsupported {area:.0f} mm2")
    ext_ok = ext[0] <= spec.BED_LIMIT and ext[1] <= spec.BED_LIMIT
    check("bezel bed fit", ext_ok, f"{ext[0]:.1f} x {ext[1]:.1f}")
    return m
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

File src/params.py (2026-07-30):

"""Design parameters for the Touch Display 2 10-inch mount parts.

Coordinate system (all parts except the stand's ground features): display
centre at XY origin, X right, Y up (portrait), Z=0 at the nominal FRONT
surface of the lens glass, +Z pointing BEHIND the display. The display body
occupies z ~0.15..8.75 at its rim when seated (see SHELF_FRONT_Z) and its
deepest features (Pi standoffs) reach z 16.2..17.25.

ARCHITECTURE (v2, after the round-1 insertion audit): the wall mount is
FRONT-LOADING. The body is an open-fronted shadow box with an internal
shelf ring; the display (with Pi attached) drops in from the front and its
chassis rim rests on the shelf. A slim bezel then snaps over the body's
recessed front band — the lap seam doubles as the frame's shadow reveal —
holding the glass against felt. The rear stays permanently featured
(keyhole tabs, vents, cable slot) because nothing is ever inserted from
the rear except the small posts-only cover, which passes below the tabs.

Everything here is a design choice layered on top of src/spec.py (the
transcribed drawing). Change values here, re-run build_all.py, and the
verification suite still has to pass.
"""

import spec

# ------------------------------------------------------------ shared shell
WALL = 3.3                          # body wall thickness (full section)
CAV_W = spec.UNIT_W + 2 * spec.FIT_CLEAR          # 162.36
CAV_H = spec.UNIT_H + 2 * spec.FIT_CLEAR          # 247.926
CAV_R = spec.UNIT_CORNER_R + spec.FIT_CLEAR       # 5.3
OUT_W = CAV_W + 2 * WALL                          # 168.96
OUT_H = CAV_H + 2 * WALL                          # 254.526
OUT_R = CAV_R + WALL                              # 8.6

# ------------------------------------------------------------------ shelf
# The display's chassis rim (rear face at spec.EDGE_T = 8.6 nominal) rests
# on this ring; the shelf sets the display's depth datum.
SHELF_FRONT_Z = spec.EDGE_T + 0.15  # 8.75 (0.15 nominal float, felt absorbs)
SHELF_T = 6.0                       # shelf ring thickness (z)
SHELF_OPEN_W = 135.0                # clears bobbins (±65.9); ~4.2 mm seat
                                    # strip on the display's rear plate
SHELF_OPEN_H = 220.0                # clears bobbins (±89); ~4.4 mm seat strip
SHELF_OPEN_R = 8.0
GLASS_Z = SHELF_FRONT_Z - spec.EDGE_T             # 0.15 nominal glass plane

# ------------------------------------------------------------------ bezel
# Face plate + outer skirt lapping over the body's recessed front band.
BEZEL_FACE_T = 3.0
BEZEL_PAD_GAP = 1.0                 # plate back to glass: 2 mm soft EVA foam
                                    # pads compressed ~50%, tolerant of the
                                    # drawing's +/-0.5 depth uncertainty
BEZEL_FRONT_Z = GLASS_Z - BEZEL_PAD_GAP - BEZEL_FACE_T    # -3.85
BEZEL_BACK_Z = BEZEL_FRONT_Z + BEZEL_FACE_T               # -0.4
SKIRT_T = 1.6
SKIRT_DEPTH = 6.3                   # skirt beyond the plate back: covers the
                                    # tongue slits (top 5.35) with margin and
                                    # makes the seam reveal a true 1.5 mm
LAP_CLEAR = 0.25                    # per side, skirt over body band
LIP_MARGIN = 2.5                    # bezel opening beyond the active area
LIP_OPEN_W = spec.ACTIVE_W + 2 * LIP_MARGIN       # 140.36
LIP_OPEN_H = spec.ACTIVE_H + 2 * LIP_MARGIN       # 221.576
LIP_OPEN_R = 3.0
LIP_OPEN_CY = spec.ACTIVE_CY_OFFSET               # active area sits high
FRONT_CHAMFER = 2.25                # bezel outer face arris
MAT_BEVEL = 2.0                     # 45 deg bevel on the opening (mat cue)
LINER_GROOVE_W = 1.5                # face shadow-gap "liner" ring
LINER_GROOVE_D = 0.6
LINER_GROOVE_INSET = 3.75           # from the outer edge to groove outer wall

# body front band that the skirt laps over
BAND_TOP_Z = BEZEL_BACK_Z + 0.3                    # -0.55: 0.3 stop gap so the
                                                   # snap, not the rim, sets depth
BAND_DEPTH = SKIRT_DEPTH + 1.2                     # 7.5: with the 0.3 stop gap
                                                   # this yields a TRUE 1.5 mm
                                                   # seam reveal (band end 6.95,
                                                   # skirt end 5.45)
BAND_OUT_W = OUT_W - 2 * (SKIRT_T + LAP_CLEAR)     # 165.26
BAND_OUT_H = OUT_H - 2 * (SKIRT_T + LAP_CLEAR)     # 250.826
BAND_OUT_R = OUT_R - (SKIRT_T + LAP_CLEAR)         # 6.75
BAND_CHAMFER_RUN = 2.25                            # band -> full outline, 45ish
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

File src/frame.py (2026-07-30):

"""Part A1: shadow-box body of the wall frame (one piece, prints
REAR-FACE-DOWN).

Front-loading: the display (with Pi attached) drops in from the front and
its chassis rim rests on the internal shelf ring; the bezel (bezel.py) then
snaps over the recessed front band. The rear keeps the keyhole hang tabs,
hidden side vents, and the bottom cable slot; the posts-only cover
(cover.py) enters from the rear, passing below the tabs.

Printed rear-face-down: the keyhole tabs lie solid on the bed (no bridges),
the band->full-outline loft faces upward, and the shelf ring carries a
45-degree chamfer on its rear side so its only support-free-critical face
(the seat itself) prints as a clean top surface.
"""

from build123d import *

import spec
import params as p


def _nub(wall: str, along: float) -> Part:
    """Snap nub on the band: 45-deg lead-in, steeper retention face."""
    half_w = p.BAND_OUT_W / 2
    half_h = p.BAND_OUT_H / 2
    embed = 0.6
    prof = [
        (-embed, p.NUB_Z0),
        (p.NUB_PROUD, p.NUB_Z0 + p.NUB_LEAD_RUN),
        (p.NUB_PROUD, p.NUB_Z1 - p.NUB_HOLD_RUN),
        (-embed, p.NUB_Z1),
    ]
    sk = Plane.XZ * Polygon(*prof, align=None)
    nub = extrude(sk, amount=p.NUB_LEN / 2, both=True)
    if wall == "left":
        return Pos(-half_w, along, 0) * Rot(0, 0, 180) * nub
    if wall == "right":
        return Pos(half_w, along, 0) * nub
    if wall == "top":
        return Pos(along, half_h, 0) * Rot(0, 0, 90) * nub
    return Pos(along, -half_h, 0) * Rot(0, 0, -90) * nub


def _tongue_slits(wall: str, along: float) -> list:
    """Two through-cuts that free a cantilever tongue under each nub.

    The tongue (root on one side, ~18 mm free length) lets the nub deflect
    inward at ~2 N instead of forcing the rigid skirt to stretch. Both slits
    hide behind the bezel skirt (which covers the band to z 5.45).
    """
    cuts = []
    tip = along + p.NUB_TIP_OFFSET
    root = tip - p.TONGUE_LEN
    # vertical slit at the tip end
    v_len = p.TONGUE_SLIT_TOP - (p.BAND_TOP_Z - 0.5)
    v = Box(6.0, p.TONGUE_SLIT_W, v_len)
    # horizontal slit separating the tongue's top edge
    h_len = tip + p.TONGUE_SLIT_W - root
    h = Box(6.0, h_len, p.TONGUE_SLIT_TOP - p.TONGUE_TOP_Z)
    half_w = p.BAND_OUT_W / 2 - 0.7
    half_h = p.BAND_OUT_H / 2 - 0.7
    for box, cy, cz in (
        (v, tip + p.TONGUE_SLIT_W / 2, p.BAND_TOP_Z - 0.5 + v_len / 2),
        (h, (root + tip + p.TONGUE_SLIT_W) / 2, (p.TONGUE_TOP_Z + p.TONGUE_SLIT_TOP) / 2),
    ):
        if wall == "left":
            cuts.append(Pos(-half_w, cy, cz) * box)
        elif wall == "right":
            cuts.append(Pos(half_w, cy, cz) * box)
        elif wall == "top":
            cuts.append(Pos(cy, half_h, cz) * Rot(0, 0, 90) * box)
        else:
            cuts.append(Pos(cy, -half_h, cz) * Rot(0, 0, 90) * box)
    return cuts


def _keyhole_cut(sx: float) -> Part:
    entry = Pos(sx * p.KEYHOLE_X, p.KEYHOLE_ENTRY_Y) * Circle(p.KEYHOLE_ENTRY_D / 2)
    slot = Pos(sx * p.KEYHOLE_X, p.KEYHOLE_ENTRY_Y + p.KEYHOLE_SLOT_LEN / 2) * Rectangle(
        p.KEYHOLE_SLOT_W, p.KEYHOLE_SLOT_LEN
    )
    tip = Pos(sx * p.KEYHOLE_X, p.KEYHOLE_ENTRY_Y + p.KEYHOLE_SLOT_LEN) * Circle(
        p.KEYHOLE_SLOT_W / 2
    )
    sk = entry + slot + tip
    return extrude(Pos(0, 0, p.KEYHOLE_TAB_Z - 0.5) * sk, amount=p.KEYHOLE_TAB_T + 1)


def build_frame() -> Part:
    band_end = p.BAND_TOP_Z + p.BAND_DEPTH                     # 6.95
    trans_end = band_end + p.BAND_CHAMFER_RUN                  # 8.35

    # shell: recessed band -> chamfer transition -> full section ---------
    band = Pos(0, 0, p.BAND_TOP_Z) * extrude(
        RectangleRounded(p.BAND_OUT_W, p.BAND_OUT_H, p.BAND_OUT_R),
        amount=p.BAND_DEPTH,
    )
    trans = loft(
        [
            Pos(0, 0, band_end) * RectangleRounded(p.BAND_OUT_W, p.BAND_OUT_H, p.BAND_OUT_R),
            Pos(0, 0, trans_end) * RectangleRounded(p.OUT_W, p.OUT_H, p.OUT_R),
        ]
    )
    body_main = Pos(0, 0, trans_end) * extrude(
        RectangleRounded(p.OUT_W, p.OUT_H, p.OUT_R),
        amount=p.FRAME_REAR_Z - trans_end,
    )
    frame = band + trans + body_main

    # through cavity (front-loading) -------------------------------------
    frame -= Pos(0, 0, p.BAND_TOP_Z - 1) * extrude(
        RectangleRounded(p.CAV_W, p.CAV_H, p.CAV_R),
        amount=p.FRAME_REAR_Z - p.BAND_TOP_Z + 2,
    )

    # shelf ring with a 45-degree rear chamfer (printable rear-face-down):
    # solid from the seat plane back to where the chamfer meets the wall,
    # minus the straight opening prism, minus a lofted void that flares
    # from the opening out to the cavity at 45 degrees.
    protrusion = max(
        (p.CAV_W - p.SHELF_OPEN_W) / 2, (p.CAV_H - p.SHELF_OPEN_H) / 2
    )                                                           # 11.97
    shelf_rear = p.SHELF_FRONT_Z + p.SHELF_T                    # 14.75
    # 1.55 x rise keeps even the corner facets of the loft (whose run is the
    # diagonal of both protrusions) comfortably under a 45-degree overhang
    chamfer_end = shelf_rear + 1.55 * protrusion                # ~36.4
    shelf_outer = RectangleRounded(p.CAV_W + 2, p.CAV_H + 2, p.CAV_R + 1)
    shelf_inner = RectangleRounded(p.SHELF_OPEN_W, p.SHELF_OPEN_H, p.SHELF_OPEN_R)
    shelf = Pos(0, 0, p.SHELF_FRONT_Z) * extrude(
        shelf_outer, amount=chamfer_end - p.SHELF_FRONT_Z
    )
    shelf -= Pos(0, 0, p.SHELF_FRONT_Z - 1) * extrude(
        shelf_inner, amount=p.SHELF_T + 1
    )
    shelf -= loft(
        [
            Pos(0, 0, shelf_rear) * shelf_inner,
            Pos(0, 0, chamfer_end)
            * RectangleRounded(p.CAV_W, p.CAV_H, p.CAV_R),
        ]
    )
    frame += shelf

    # snap nubs on compliant tongues -------------------------------------
    nubs = (
        [("left", y) for y in p.NUB_SIDE_YS]
        + [("right", y) for y in p.NUB_SIDE_YS]
        + [("top", x) for x in p.NUB_TOP_XS]
        + [("bottom", x) for x in p.NUB_BOT_XS]
    )
    for wall, along in nubs:
        frame += _nub(wall, along)
    for wall, along in nubs:
        for cut in _tongue_slits(wall, along):
            frame -= cut

    # finger reliefs for bezel removal: shallow scallops in the bottom
    # band running from under the skirt edge out through the reveal, so a
    # fingernail gets real purchase behind the skirt (round-3 audit: the
    # earlier fully-buried version was unreachable)
    band_end_z = p.BAND_TOP_Z + p.BAND_DEPTH
    for x in p.RELIEF_XS:
        frame -= Pos(
            x, -(p.BAND_OUT_H / 2 - p.RELIEF_D / 2 + 0.01), (3.0 + band_end_z + 0.4) / 2
        ) * Box(p.RELIEF_W, p.RELIEF_D, band_end_z + 0.4 - 3.0)
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

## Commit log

2026-07-30 Initial commit: Touch Display 2 mounts (wall frame, stand, fit coupons)
    Parametric build123d CAD, verification harness, exported STL/3MF,
    renders, and print-ready files, plus CLAUDE.md project guidance.
    [_display_reference.3mf, _display_reference.stl, bezel.3mf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]
2026-07-30 Sync to latest: camera chin pod, 200mm cable BOM, spec source docs
    Adds the Camera Module 3 chin pod (J-hooks into the bottom intake vents,
    FoV-verified, 85-check suite), the 200mm Pi 5 adapter cable BOM entry, the
    official product-brief PDF + full-res drawing crops that the spec
    transcription and audit workflow reference, and a README hero render.
    Claude-Session: https://claude.ai/code/session_01NfMAXvnnKK2RSEKjrFwEGb
    [camera-pod.stl]
2026-07-30 Add missing 3MF files: camera pod + pre-rotated print/ copies
    Geometry-only 3MF conversions of the existing STLs (identical meshes,
    build item included so slicers place the part).
    [bezel.3mf, camera-pod.3mf, cover.3mf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]
